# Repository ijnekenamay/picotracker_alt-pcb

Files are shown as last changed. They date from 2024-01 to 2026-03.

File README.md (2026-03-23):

# Picotracker Alt-PCB

~~**Do not fabricate! There could be a major mistake around MIDI!!**~~

**[Alex fixed it!](https://github.com/ijnekenamay/picotracker_alt-pcb/pull/2) We should be able to go ahead with production now.**

This project is about [democloid picoTracker's](https://github.com/democloid/picoTracker/) alternative PCB.
Inexpensive handheld devices can be built to run LittleGPTracker(a.k.a piggytracker).
It basically follows the original DIY version, with a few modifications of my own. They are described below.

[You can see it in motion here.](https://www.instagram.com/p/C2BvngaruZN/?utm_source=ig_web_copy_link&igsh=MzRlODBiNWFlZA==)

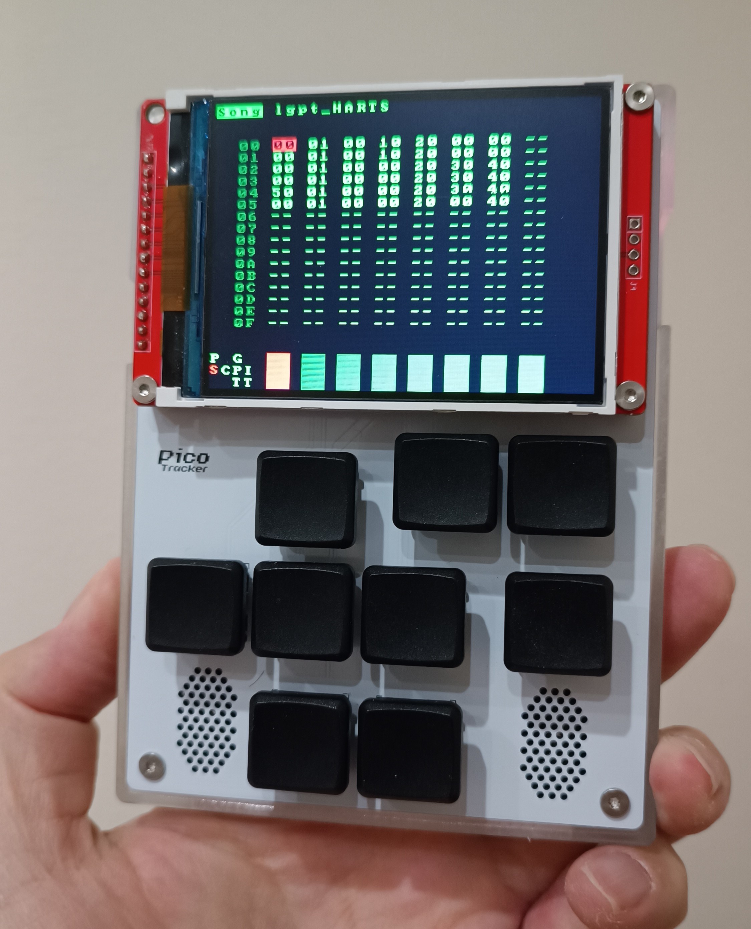
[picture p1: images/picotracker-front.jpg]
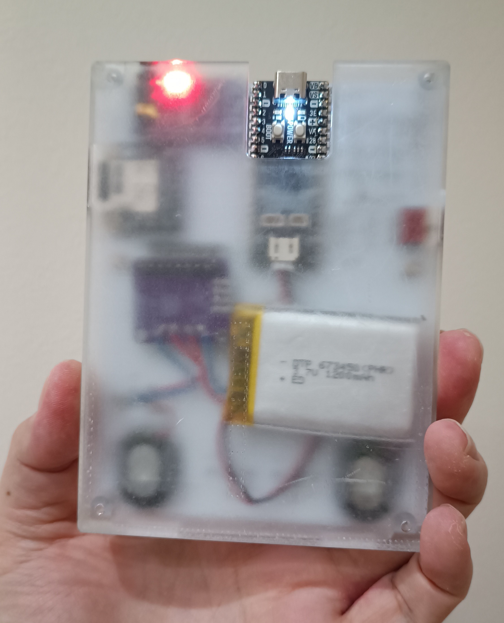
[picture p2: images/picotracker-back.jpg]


## Feature

- The two PCBs act as an enclosure by sandwiching the components together.
- I wanted a module for the charging function and plenty of memory, so I went with the [Pimoroni Pico LiPo](https://shop.pimoroni.com/products/pimoroni-pico-lipo).
- I wanted a micro-speaker like the DirtywaveM8, so I added one... and a Class D amplifier module.
- A speaker kill switch has been added.
- This also uses Kailh Choc V1 for the keycaps because of my personal taste.
- You can change any specification by yourself if you have access to Kicad.
- [See image for values of components around MIDI.](https://raw.githubusercontent.com/ijnekenamay/picotracker_alt-pcb/main/images/MIDI_resistor_value.jpg)
- I designed a back panel that could be output with a 3D printer because I felt the microspeaker needed box resonance. Also, if you would like to try it, please see the STL data. Feedback is welcome.
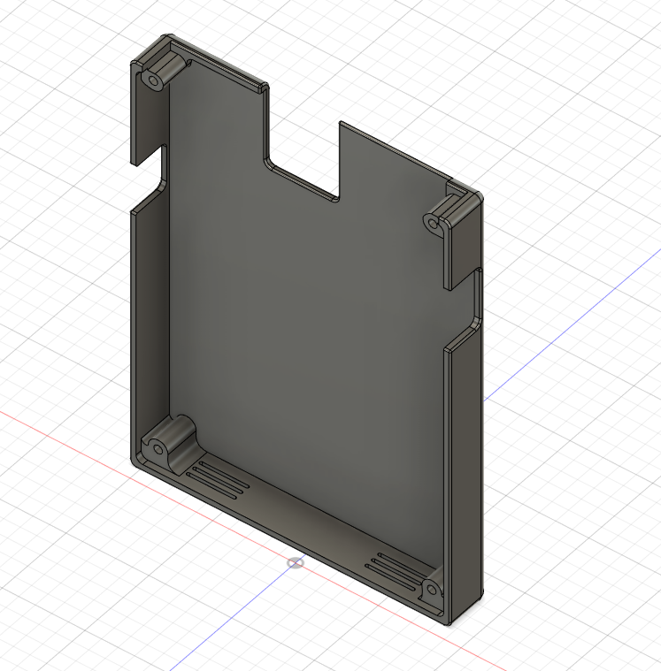
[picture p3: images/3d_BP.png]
- 

## BOM

| Value | Quantity | info |
| --- | --- | --- |
| Pimoroni Pico LiPo 16MB | 1 | [URL](https://shop.pimoroni.com/products/pimoroni-pico-lipo)　 [URL(Japan only)](https://akizukidenshi.com/catalog/g/g116997/) |
| ILI9341 3.2" display | 1 | [URL](https://www.aliexpress.us/item/3256802819098352.html) |
| GY-PCM5102 DAC module | 1 | [URL](https://www.aliexpress.us/item/3256802711963831.html) |
| Adafruit Micro SD SPI or SDIO Card Breakout Board | 1 | [URL](https://www.adafruit.com/product/4682) |
| Kailh Choc V1 key switch | 9 | |
| keycaps | 9 | |
| max98306 class D amp | 1 | [URL](https://ja.aliexpress.com/item/1005004990814956.html) |
| Micro speaker | 2 | [URL](https://akizukidenshi.com/catalog/g/gP-12494/) |
| SMD Slide Switch | 1 | on-on [The footprint uses a 6-pin one.](https://akizukidenshi.com/download/ds/switronic/IS-2245S-G.PDF) |
| PJ-311 3.5mm Stereo Jack | 2 | |
| 1n4148 | 1 | SOD-323 |
| 47R | 2 | 1608 |
| 220R | 1 | 1608 |
| 470R | 1 | 1608 |
| 10k | 1 | 1608 |
| 6N138 | 1 | DIP-8 SMD(Just cut off the normal DIP8 leg.) |
| lipo battery | 1 | I use 1200mAh and need less recharging. |
| other | \* | Other pin headers and sockets. We need standoff bolts, nuts, screws, and lots of them. |

It is recommended to use short pin headers and to solder directly without using sockets. At the very least, the effective depth of the 3D printer back panel is only 11 mm, which would interfere with the use of pin sockets. (but i wanted to go thin)

The images below are prototype versions and differ from the actual data.

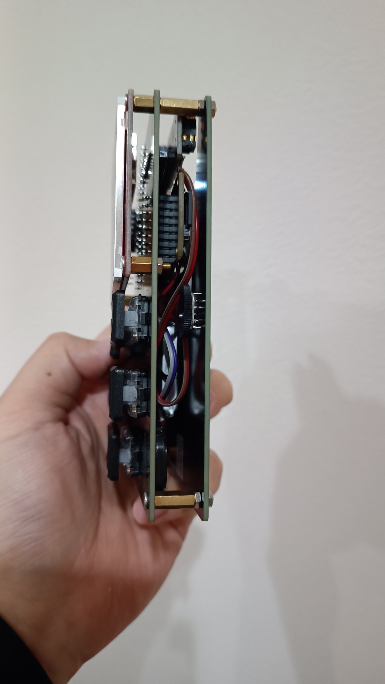
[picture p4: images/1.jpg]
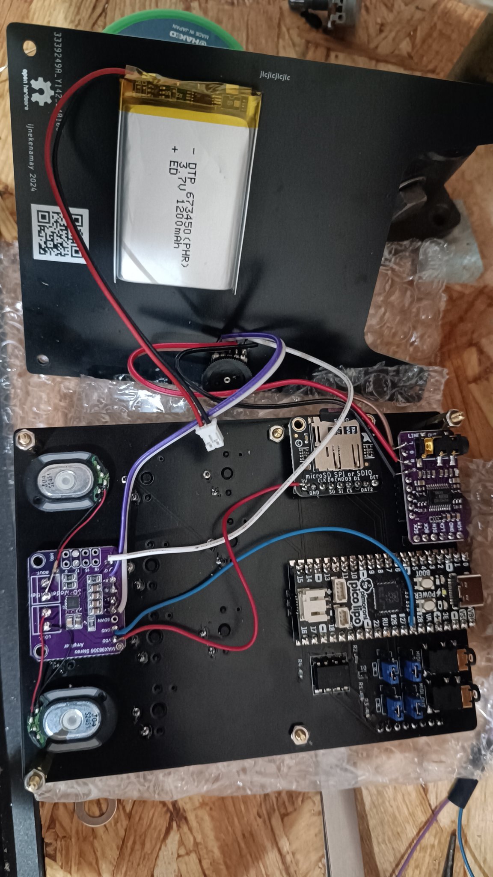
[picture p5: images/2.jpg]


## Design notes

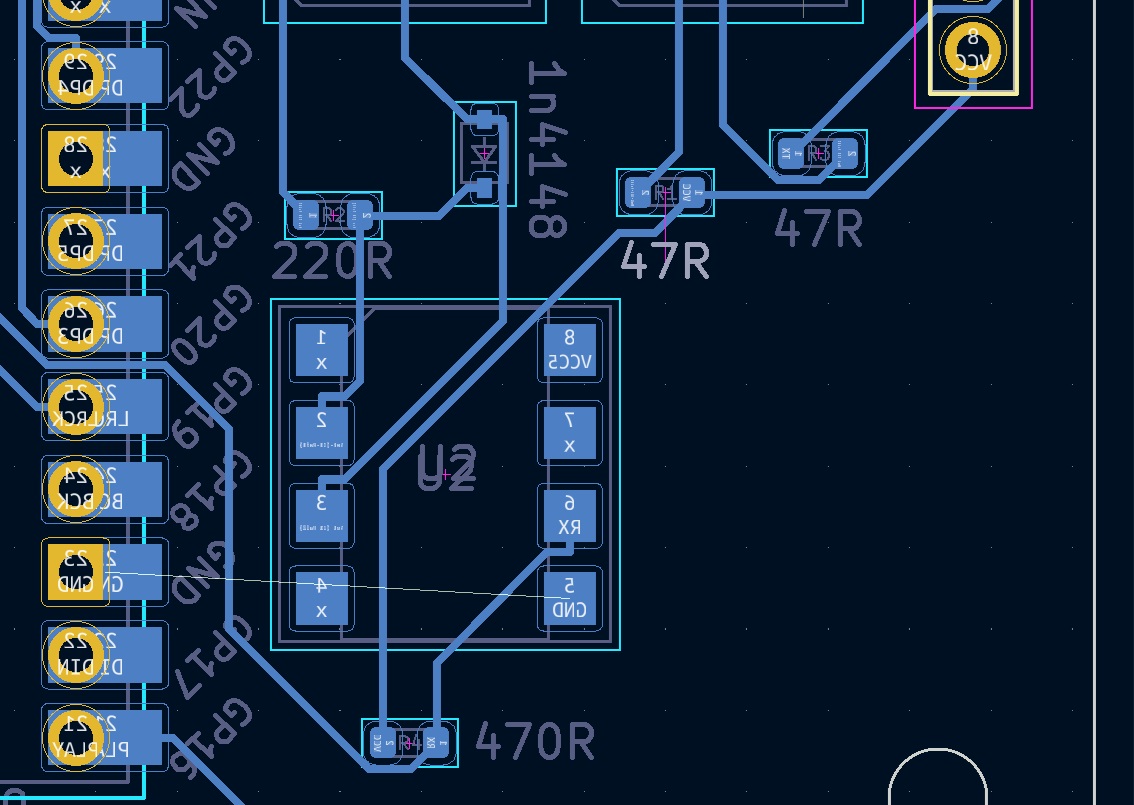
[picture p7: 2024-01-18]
images/MIDI_resistor_value.jpg

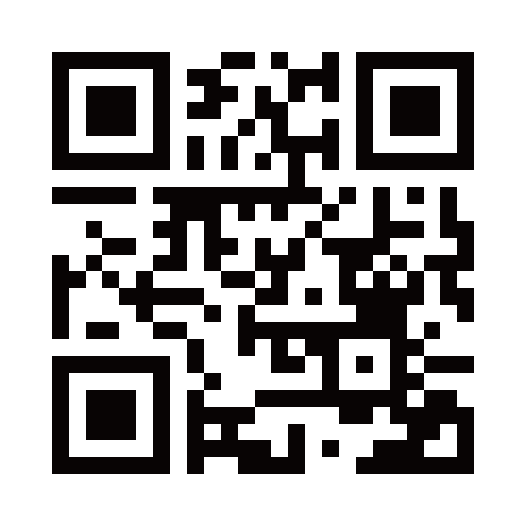
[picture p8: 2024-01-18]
kicad/qr.bmp

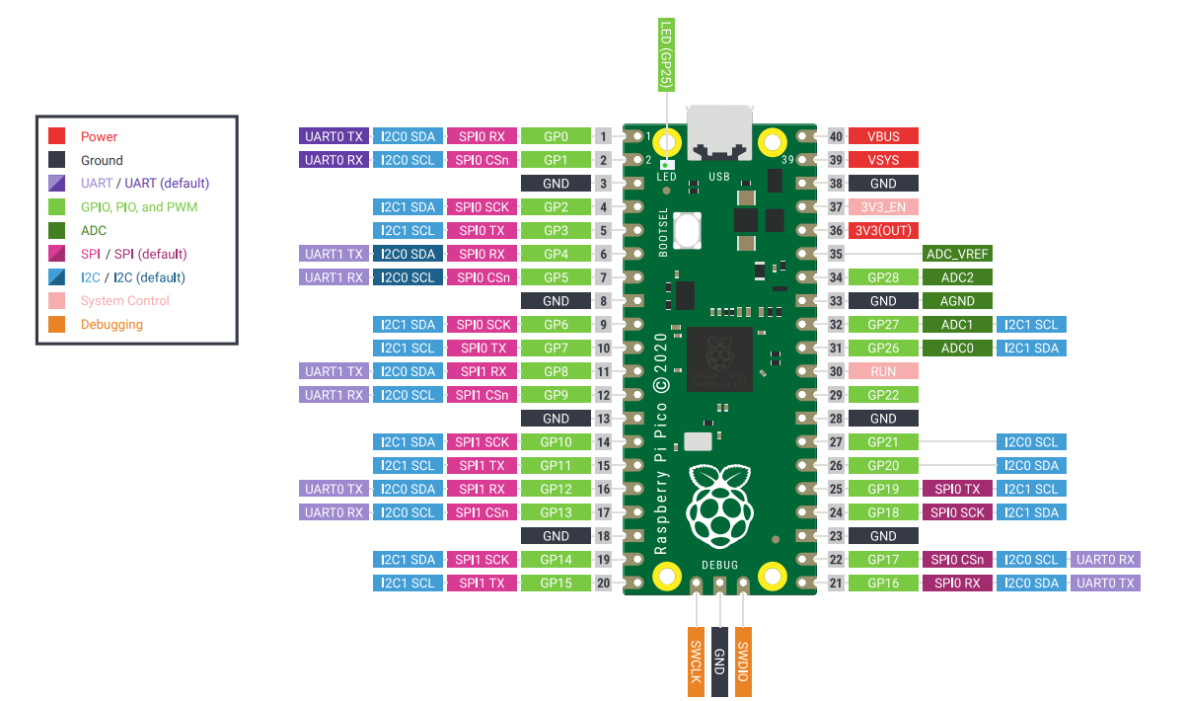
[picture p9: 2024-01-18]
kicad/Pico_pinhaiti.png

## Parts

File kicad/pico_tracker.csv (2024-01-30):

Source: | C:\Users\yaman\OneDrive\ドキュメント\KiCad\pico_tracker\pico_tracker.kicad_sch
Date: | 2024/01/18 22:58:37
Tool: | Eeschema (6.0.7)
Generator: | C:\Program Files\KiCad\6.0\bin\scripting\plugins/bom_csv_grouped_by_value.py
Component Count: | 28
Individual Components:
Item | Qty | Reference(s) | Value | LibPart | Footprint | Datasheet
 |  | D1 | 1n4148 | Device:D | Diode_SMD:D_SOD-323 | ~
 |  | J1 | MIDI_OUT | Connector:AudioJack3 | Connector_Audio:Jack_3.5mm_PJ311_Horizontal | ~
 |  | J2 | MIDI_IN | Connector:AudioJack3 | Connector_Audio:Jack_3.5mm_PJ311_Horizontal | ~
 |  | J3 | MIDI_IN_A_B_VCC | Connector:Conn_01x03_Female | Connector_PinHeader_2.54mm:PinHeader_1x03_P2.54mm_Vertical | ~
 |  | J4 | MIDI_IN_A_B_DATA | Connector:Conn_01x03_Female | Connector_PinHeader_2.54mm:PinHeader_1x03_P2.54mm_Vertical | ~
 |  | J5 | MIDI_OUT_A_B_VCC | Connector:Conn_01x03_Female | Connector_PinHeader_2.54mm:PinHeader_1x03_P2.54mm_Vertical | ~
 |  | J6 | MIDI_OUT_A_B_DATA | Connector:Conn_01x03_Female | Connector_PinHeader_2.54mm:PinHeader_1x03_P2.54mm_Vertical | ~
 |  | J7 | DISPLAY | Connector:Conn_01x08_Female | Connector_PinHeader_2.54mm:PinHeader_1x08_P2.54mm_Vertical | ~
 |  | J8 | SDCARD | Connector:Conn_01x09_Female | Connector_PinHeader_2.54mm:PinHeader_1x09_P2.54mm_Vertical | ~
 |  | J9 | KILL_SWITCH | Connector:Conn_01x06_Female | Connector_PinHeader_2.54mm:PinHeader_2x03_P2.54mm_Vertical_SMD | ~
 |  | J10 | DclassAMP | Connector:Conn_01x09_Female | Connector_PinHeader_2.54mm:PinHeader_1x09_P2.54mm_Vertical | ~
 |  | J11 | MASTER_VOLUME | Connector:Conn_01x06_Female | Connector_PinHeader_2.54mm:PinHeader_2x03_P2.54mm_Vertical_SMD | ~
 |  | R1 | 47R | Device:R | Resistor_SMD:R_0603_1608Metric | ~
 |  | R2 | 220R | Device:R | Resistor_SMD:R_0603_1608Metric | ~
 |  | R3 | 47R | Device:R | Resistor_SMD:R_0603_1608Metric | ~
 |  | R4 | 470R | Device:R | Resistor_SMD:R_0603_1608Metric | ~
 |  | SW1 | LEFT | Switch:SW_Push | Button_Switch_Keyboard:SW_PG1350 | ~
 |  | SW2 | DOWN | Switch:SW_Push | Button_Switch_Keyboard:SW_PG1350 | ~
 |  | SW3 | RIGHT | Switch:SW_Push | Button_Switch_Keyboard:SW_PG1350 | ~
 |  | SW4 | UP | Switch:SW_Push | Button_Switch_Keyboard:SW_PG1350 | ~
 |  | SW5 | RT | Switch:SW_Push | Button_Switch_Keyboard:SW_PG1350 | ~
 |  | SW6 | B | Switch:SW_Push | Button_Switch_Keyboard:SW_PG1350 | ~
 |  | SW7 | A | Switch:SW_Push | Button_Switch_Keyboard:SW_PG1350 | ~
 |  | SW8 | LT | Switch:SW_Push | Button_Switch_Keyboard:SW_PG1350 | ~
 |  | SW9 | PLAY | Switch:SW_Push | Button_Switch_Keyboard:SW_PG1350 | ~
 |  | U1 | Pico | RPi_Pico:Pico | RPi_Pico:RPi_Pico_SMD_TH
 |  | U2 | 6N138 | Isolator:6N138 | Package_DIP:DIP-8_W7.62mm_SMDSocket_SmallPads | http://www.onsemi.com/pub/Collateral/HCPL2731-D.pdf
 |  | U3 | PCM5102_Module | Audio:PCM5102_Module | Connector_PinHeader_2.54mm:PinHeader_1x06_P2.54mm_Vertical
Collated Components:
Item | Qty | Reference(s) | Value | LibPart | Footprint | Datasheet
1 | 1 | D1 | 1n4148 | Device:D | Diode_SMD:D_SOD-323 | ~
2 | 1 | J1 | MIDI_OUT | Connector:AudioJack3 | Connector_Audio:Jack_3.5mm_PJ311_Horizontal | ~
3 | 1 | J2 | MIDI_IN | Connector:AudioJack3 | Connector_Audio:Jack_3.5mm_PJ311_Horizontal | ~
4 | 1 | J3 | MIDI_IN_A_B_VCC | Connector:Conn_01x03_Female | Connector_PinHeader_2.54mm:PinHeader_1x03_P2.54mm_Vertical | ~
5 | 1 | J4 | MIDI_IN_A_B_DATA | Connector:Conn_01x03_Female | Connector_PinHeader_2.54mm:PinHeader_1x03_P2.54mm_Vertical | ~
6 | 1 | J5 | MIDI_OUT_A_B_VCC | Connector:Conn_01x03_Female | Connector_PinHeader_2.54mm:PinHeader_1x03_P2.54mm_Vertical | ~
7 | 1 | J6 | MIDI_OUT_A_B_DATA | Connector:Conn_01x03_Female | Connector_PinHeader_2.54mm:PinHeader_1x03_P2.54mm_Vertical | ~
8 | 1 | J7 | DISPLAY | Connector:Conn_01x08_Female | Connector_PinHeader_2.54mm:PinHeader_1x08_P2.54mm_Vertical | ~
9 | 1 | J8 | SDCARD | Connector:Conn_01x09_Female | Connector_PinHeader_2.54mm:PinHeader_1x09_P2.54mm_Vertical | ~
10 | 1 | J9 | KILL_SWITCH | Connector:Conn_01x06_Female | Connector_PinHeader_2.54mm:PinHeader_2x03_P2.54mm_Vertical_SMD | ~
11 | 1 | J10 | DclassAMP | Connector:Conn_01x09_Female | Connector_PinHeader_2.54mm:PinHeader_1x09_P2.54mm_Vertical | ~
12 | 1 | J11 | MASTER_VOLUME | Connector:Conn_01x06_Female | Connector_PinHeader_2.54mm:PinHeader_2x03_P2.54mm_Vertical_SMD | ~
13 | 2 | R1, R3 | 47R | Device:R | Resistor_SMD:R_0603_1608Metric | ~
14 | 1 | R2 | 220R | Device:R | Resistor_SMD:R_0603_1608Metric | ~
15 | 1 | R4 | 470R | Device:R | Resistor_SMD:R_0603_1608Metric | ~
16 | 1 | SW1 | LEFT | Switch:SW_Push | Button_Switch_Keyboard:SW_PG1350 | ~
17 | 1 | SW2 | DOWN | Switch:SW_Push | Button_Switch_Keyboard:SW_PG1350 | ~
18 | 1 | SW3 | RIGHT | Switch:SW_Push | Button_Switch_Keyboard:SW_PG1350 | ~
19 | 1 | SW4 | UP | Switch:SW_Push | Button_Switch_Keyboard:SW_PG1350 | ~
20 | 1 | SW5 | RT | Switch:SW_Push | Button_Switch_Keyboard:SW_PG1350 | ~
21 | 1 | SW6 | B | Switch:SW_Push | Button_Switch_Keyboard:SW_PG1350 | ~
22 | 1 | SW7 | A | Switch:SW_Push | Button_Switch_Keyboard:SW_PG1350 | ~
23 | 1 | SW8 | LT | Switch:SW_Push | Button_Switch_Keyboard:SW_PG1350 | ~
24 | 1 | SW9 | PLAY | Switch:SW_Push | Button_Switch_Keyboard:SW_PG1350 | ~
25 | 1 | U1 | Pico | RPi_Pico:Pico | RPi_Pico:RPi_Pico_SMD_TH
26 | 1 | U2 | 6N138 | Isolator:6N138 | Package_DIP:DIP-8_W7.62mm_SMDSocket_SmallPads | http://www.onsemi.com/pub/Collateral/HCPL2731-D.pdf
27 | 1 | U3 | PCM5102_Module | Audio:PCM5102_Module | Connector_PinHeader_2.54mm:PinHeader_1x06_P2.54mm_Vertical

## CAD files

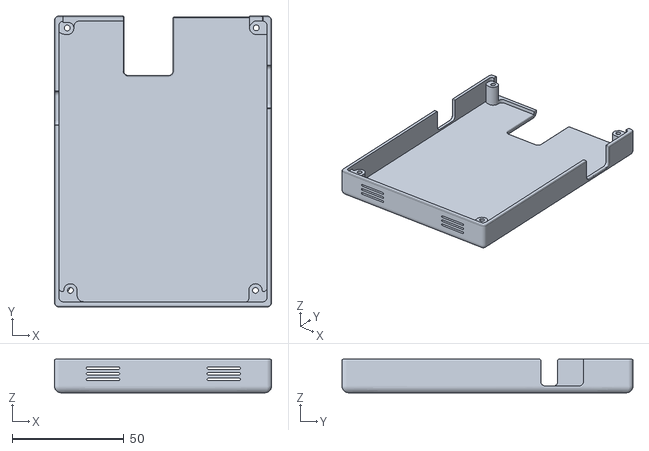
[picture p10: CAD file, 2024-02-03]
3dprinter_picotracker_backpanel.stl
97.0 x 130.0 x 15.0

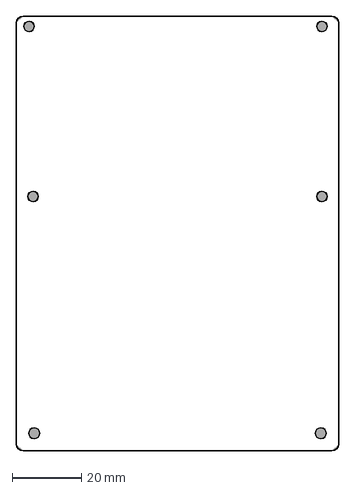
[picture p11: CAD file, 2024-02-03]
kicad/pico_tracker-Edge_Cuts.dxf
92.9 x 125.4 mm

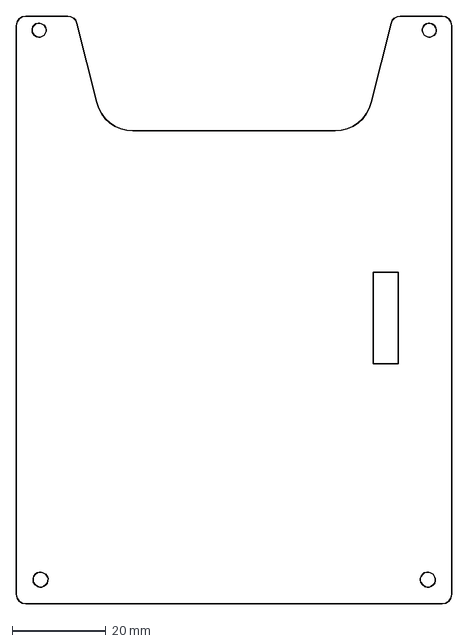
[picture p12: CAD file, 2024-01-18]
kicad/pcb_tmp.dxf
92.9 x 125.4 mm

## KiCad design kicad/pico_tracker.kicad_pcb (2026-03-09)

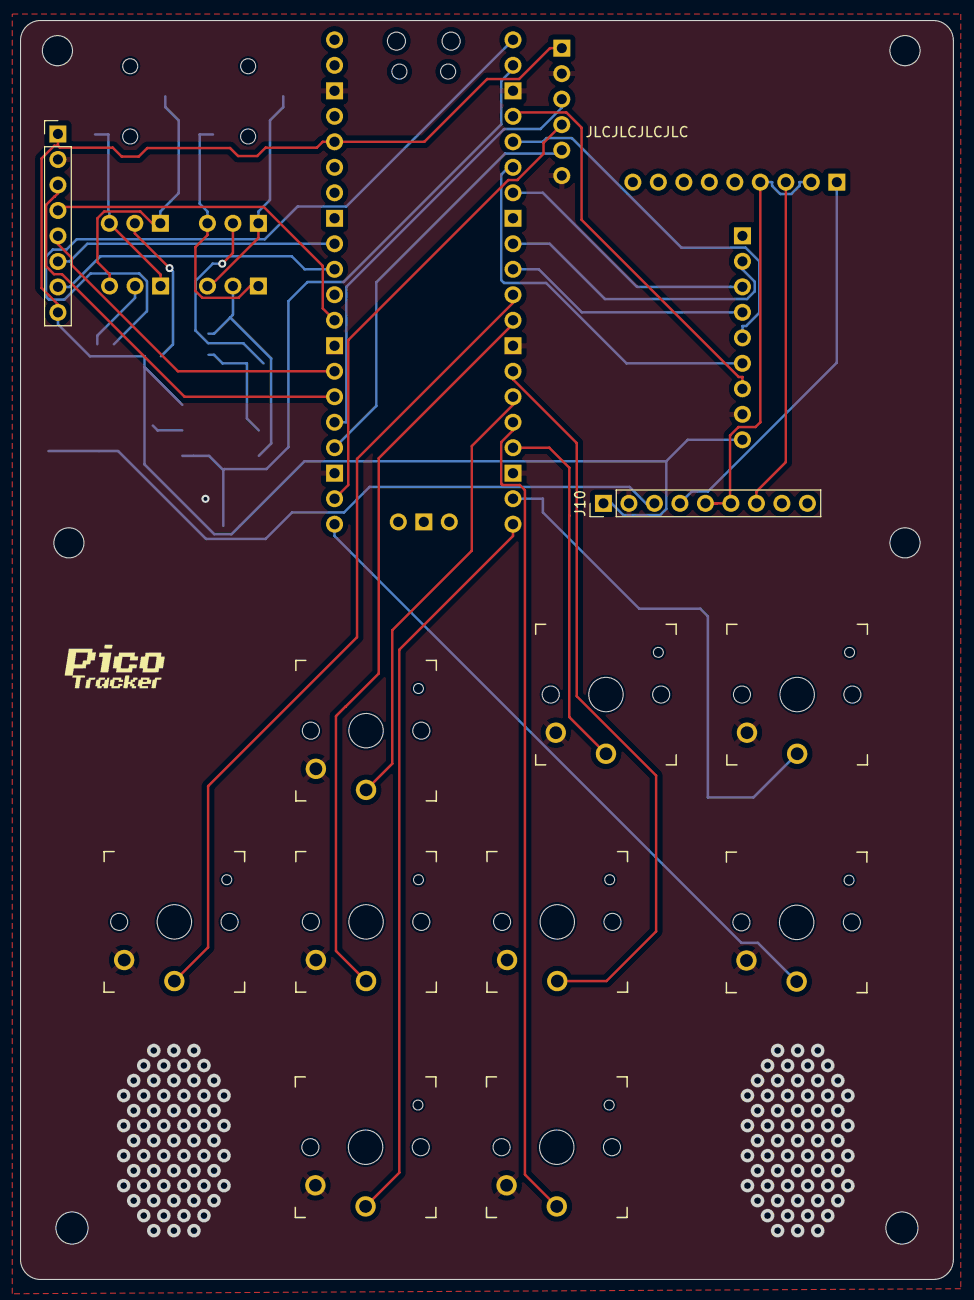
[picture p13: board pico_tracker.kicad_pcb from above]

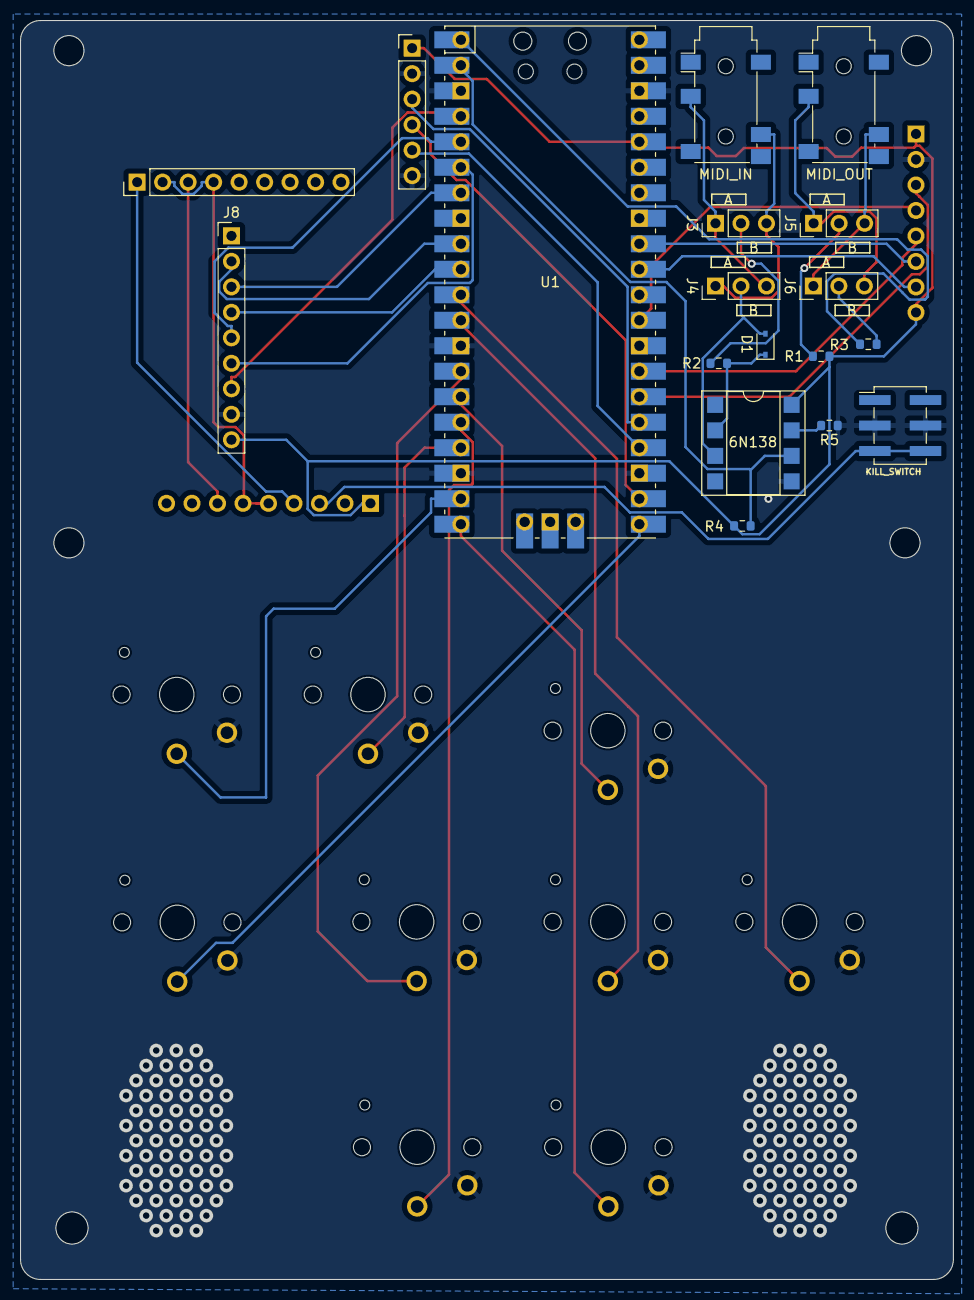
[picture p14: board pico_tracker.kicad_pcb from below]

Board: 2 copper layers, 92.9 x 125.4 mm, 30 parts (18 on the bottom side), 41 nets.

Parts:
D1: 1n4148; D_SOD-323
G1: LOGO; logo_silk
J1: MIDI_OUT; Jack_3.5mm_PJ311_Horizontal
J2: MIDI_IN; Jack_3.5mm_PJ311_Horizontal
J3: MIDI_IN_A_B_VCC; PinHeader_1x03_P2.54mm_Vertical
J4: MIDI_IN_A_B_DATA; PinHeader_1x03_P2.54mm_Vertical
J5: MIDI_OUT_A_B_VCC; PinHeader_1x03_P2.54mm_Vertical
J6: MIDI_OUT_A_B_DATA; PinHeader_1x03_P2.54mm_Vertical
J7: DISPLAY; PinHeader_1x08_P2.54mm_Vertical
J8: SDCARD; PinHeader_1x09_P2.54mm_Vertical
J9: KILL_SWITCH; PinHeader_2x03_P2.54mm_Vertical_SMD
J10: DclassAMP; PinHeader_1x09_P2.54mm_Vertical
R1, R3: 47R; R_0603_1608Metric
R2: 220R; R_0603_1608Metric
R4: 470R; R_0603_1608Metric
R5: 10k; R_0603_1608Metric
REF1: PinHeader_1x09_P2.54mm_Vertical_SMD_Pin1Left; PinHeader_1x09_P2.54mm_Vertical
SW1, SW2, SW3, SW4, SW5, SW6, SW7, SW8, SW9: SW_PG1350
U1: Pico; RPi_Pico_SMD_TH
U2: 6N138; DIP-8_W7.62mm_SMDSocket_SmallPads
U3: PCM5102_Module; PinHeader_1x06_P2.54mm_Vertical

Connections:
A: SW7.1, U1.19 (GPIO14)
AGND: J10.5, J10.6, REF1.2, REF1.4
B: SW6.1, U1.17 (GPIO13)
BCK: U1.24 (GPIO18), U3.5 (BCK)
CLK: J8.7, U1.4 (GPIO2)
D1: J8.3, U1.7 (GPIO5)
D3: J8.4, U1.10 (GPIO7)
DAT2: J8.2, U1.9 (GPIO6)
DIN: U1.22 (GPIO17), U3.4 (DIN)
DOWN: SW2.1, U1.12 (GPIO9)
DP3: J7.3, U1.26 (GPIO20)
DP4: J7.4, U1.29 (GPIO22)
DP5: J7.5, U1.27 (GPIO21)
DP6: J7.6, U1.32 (GPIO27_ADC1)
DP7: J7.7, U1.31 (GPIO26_ADC0)
GND: J7.2, J8.8, J9.2, J9.5, J10.2, R5.1, SW1.2, SW2.2, SW3.2, SW4.2, SW5.2, SW6.2, SW7.2, SW8.2, SW9.2, U1.3 (GND), U1.13 (GND), U1.18 (GND), U1.23 (GND), U1.38 (GND), U2.5 (GND), U3.2 (GND), U3.6 (SCK)
KILL_SWITCH: J9.1, J9.4, J10.3
LEFT: SW1.1, U1.11 (GPIO8)
LRCK: U1.25 (GPIO19), U3.3 (LRCK)
LT: SW8.1, U1.20 (GPIO15)
L_AMP: J10.4, REF1.1
unnamed: D1.2 (A), J4.2, U2.3 (C2)
unnamed: D1.1 (K), R2.2, U2.2 (C1)
unnamed: J3.1, J4.3
unnamed: J3.2, R2.1
unnamed: J3.3, J4.1
unnamed: J5.1, J6.3
unnamed: J5.2, R1.2
unnamed: J5.3, J6.1
unnamed: J6.2, R3.2
unnamed: R5.2, U2.7 (VO1)
PLAY: SW9.1, U1.21 (GPIO16)
RIGHT: SW3.1, U1.14 (GPIO10)
RT: SW5.1, U1.16 (GPIO12)
RX: R4.1, U1.2 (GPIO1), U2.6 (VO2)
R_AMP: J10.7, REF1.3
SI: J8.5, U1.5 (GPIO3)
SO: J8.6, U1.6 (GPIO4)
TX: R3.1, U1.1 (GPIO0)
UP: SW4.1, U1.15 (GPIO11)
VCC: J7.1, J7.8, J8.9, J10.1, R1.1, R4.2, U1.36 (3V3), U2.8 (VCC), U3.1 (VIN)

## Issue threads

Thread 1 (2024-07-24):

What are the details of the potential midi issue?

RyanParsley, 2024-07-24:
This project looks like a fun build but I noticed the warning in the readme.

Is this an issue you're investigating?

ijnekenamay, 2024-07-30:
The PCB data that is available is simply wrong for the TX/RX pins. I would like to correct it and test it, but I don't have much spare time at the moment.
It is possible to deal with the current PCB by simply reconnecting the wires.

danielrod36, 2025-05-02:
Hi! I was looking into building one, but found your warning before ordering the parts.
Are there plans to fix the issue soon? Or maybe instructions on how to reconnect the wires as you pointed out above.
Thanks in advance!

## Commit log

2026-03-06 fix: 6N138 VCC connexion and RX/TX pins flip
    [pico_tracker.kicad_pcb, pico_tracker.kicad_sch]
2026-03-06 chore: generate gerber files
    [pico_tracker-B_Cu.gbr, pico_tracker-B_Mask.gbr, pico_tracker-B_Paste.gbr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]
2026-03-06 fix: add 10k resistor to pin 7
    [pico_tracker-B_Cu.gbr, pico_tracker-B_Mask.gbr, pico_tracker-B_Paste.gbr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]
2026-03-06 docs: adds 10k resistor to readme
2026-03-06 chore: update gerber_main zip file
